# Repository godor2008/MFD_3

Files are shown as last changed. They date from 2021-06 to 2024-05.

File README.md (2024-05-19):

# MFD_3
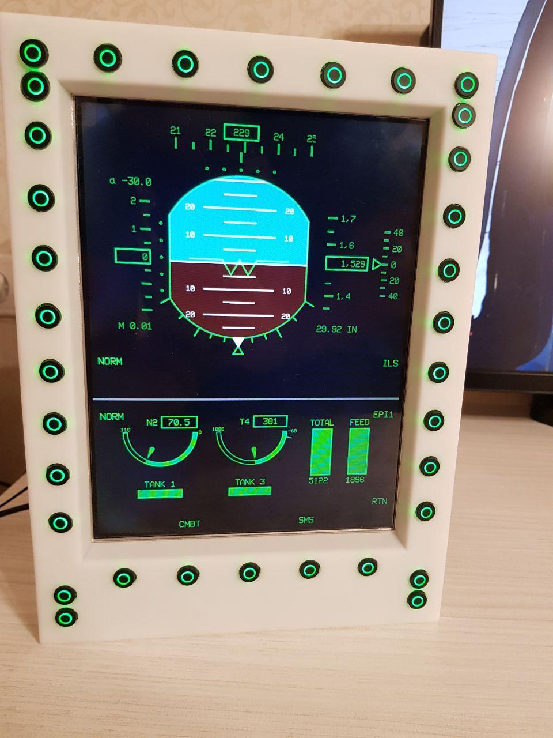
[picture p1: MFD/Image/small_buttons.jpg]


This is MFCD board for JF-17 module used in DCS World. It is similar to Thrustmaster Cougar panel, but larger. Designed to be used with 9.7 inch monitor 4:3 1024x768
Designed in Altium Designer 20

Contains output files (Gerber) and elements list for production at https://jlcpcb.com/

[Gerber zip archive](https://github.com/godor2008/MFD_3/blob/small_buttons/MFD/Project%20Outputs%20for%20Mfd3/Project%20Outputs%20for%20Mfd3.zip)
---------------
[BOM](https://github.com/godor2008/MFD_3/blob/small_buttons/MFD/Project%20Outputs%20for%20Mfd3/Bill%20of%20Materials-Mfd3.xlsx)
-------------
[Pick and Place file](https://github.com/godor2008/MFD_3/blob/small_buttons/MFD/Project%20Outputs%20for%20Mfd3/Pick%20Place%20for%20Mfd3.csv)
-----------
You may download these files and use them to order boards with SMT asssembly at https://jlcpcb.com/

Buttons you have to solder yourself.

Button used is 6*6 tactile switch with built-in LED. For example I used this https://www.aliexpress.com/item/32947533283.html
But you may find other similar buttons at alibaba.com or your local shop.
You may also add simple keycaps, for example I used this https://www.aliexpress.com/item/32918071718.html

Firmware is developed by FreeJoy https://github.com/FreeJoy-Team/FreeJoyWiki
Take a look at that project. 

Firmware may be downloaded [here](https://github.com/godor2008/MFD_3/blob/small_buttons/MFD/Firmware/FreeJoy_v1_7_1b3.hex)

This is [configuration](https://github.com/godor2008/MFD_3/blob/small_buttons/MFD/Firmware/new_FreeJoyLeft.cfg) file that contains mappings between physical and logical buttons. Should be uploaded through FreeJoy configurator after programming firmware.

Additionally you'll need to order:
Tiny [HDMI](https://vi.aliexpress.com/item/33057698628.html) 10 cm cable for extension inside case. Order 2 A1 connectors and 10cm cable


[XH 2.54 20 cm cables](https://vi.aliexpress.com/item/1005002160765607.html) for usb extension. Order 1 pack of each color

[XH 2.54 4 pin angled connectors set](https://vi.aliexpress.com/item/4000029752260.html) for usb extension. You need only two of them, so order minimal pack you can


[Usb Connector B Type vertical](https://vi.aliexpress.com/item/32947971157.html)


| | Price for 1 item, usd |  Quantity | Price |
|---|---:|---:|---:|
| HDMI board from aliexpress | 2,4 | 1 | 2,4 |
| HDMI 10 cm FFC cable | 0,038 | 1 | 0,038 |
| HDMI 10 cm FFC cable Shipping | 1,46 | 1 | 1,46 |
| M4 River Nut | 0,17 | 4 | 0,68 |
| M6 Washer | 0,025 | 4 | 0,1 |
| M3 20 mm brass standoff | 0,16 | 19 | 3,04 |
| M3x8 bolt countersink | 0,025 | 19 | 0,475 |
| M3 14 mm brass male female standoff | 0,16 | 2 | 0,32 |
| M3 washer | 0,024 | 2 | 0,048 |
| Molex HDMI connector | 4,8 | 1 | 4,8 |
| M3 7 mm brass male female standoff  | 0,13 | 2 | 0,26 |
| M3 nylon locking nuts | 0,039 | 4 | 0,156 |
| XH JST 2.54 20 cm cable | 0,055 | 4 | 0,22 |
| M3x10 bolt | 0,04 | 30 | 1,2 |
| M3 nylon locking nuts | 0,039 | 13 | 0,507 |
| M3 nut with washer | 0,025 | 15 | 0,375 |
| M3x10 screw | 0,04 | 19 | 0,76 |
| M2.5x10 bolt | 0,037 | 6 | 0,222 |
| M2.5 nylon locking nut | 0,045 | 11 | 0,495 |
| M3x16 bolt | 0,044 | 2 | 0,088 |
| M4x16 bolt | 0,1 | 4 | 0,4 |
| M2x16 bolt | 0,036 | 9 | 0,324 |
| M2 nylon locking nut | 0,052 | 9 | 0,468 |
| USB-B vertical | 1,58 | 1 | 1,58 |
| USB adapter PCB | 2 | 1 | 2 |
| Main PCB with buttons | 10,47 | 1 | 10,47 |
| LCD with controller | 52 | 1 | 52 |
| 3D printed case | 32 | 1 | 32 |
| Aluminum plates | 13,5 | 2 | 27 |
| KeyCap | 0,146| 32 | 4,672 |
| | | Total USD | 148,558 |

# Some assembly process:

# Middle plate
Make countersink holes so screw perfecty fits in it:


Prepare 19 **brass 20mm standoffs** and 19 **M3 8mm screws**:








Prepare 11 **M3 10mm screws**, 11 **M3 nuts with washer**, 11 **M3 nylon locking nuts**, 11 **small plates from steel 0.8mm-1mm** that will be used to hold LCD on place.


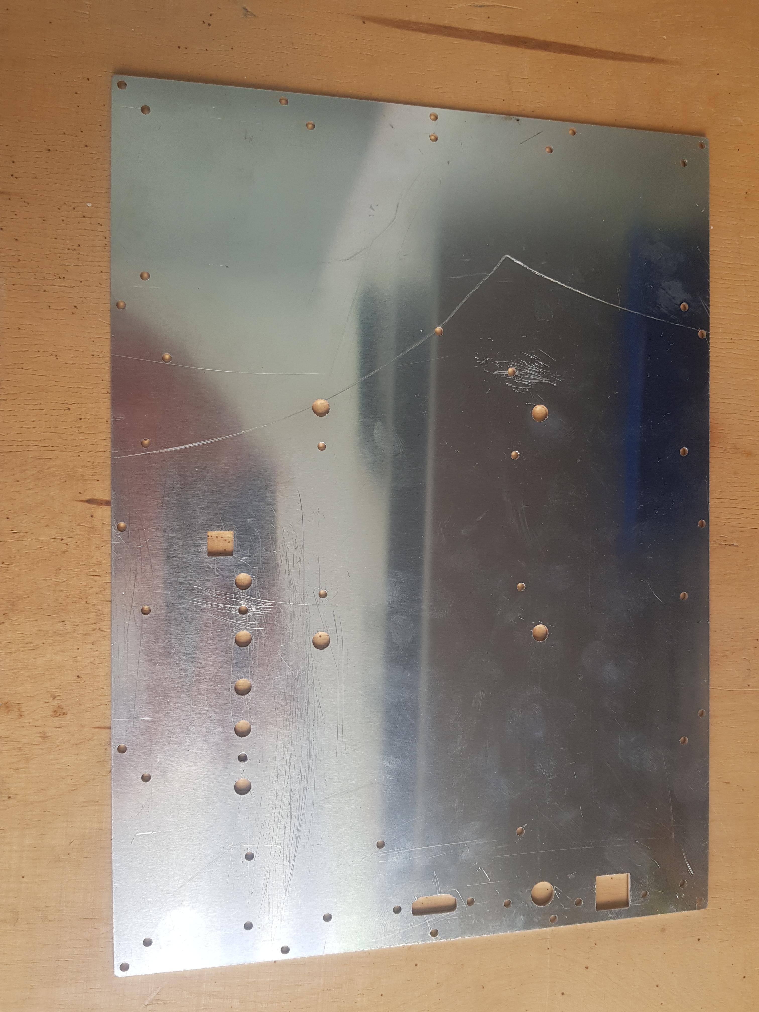
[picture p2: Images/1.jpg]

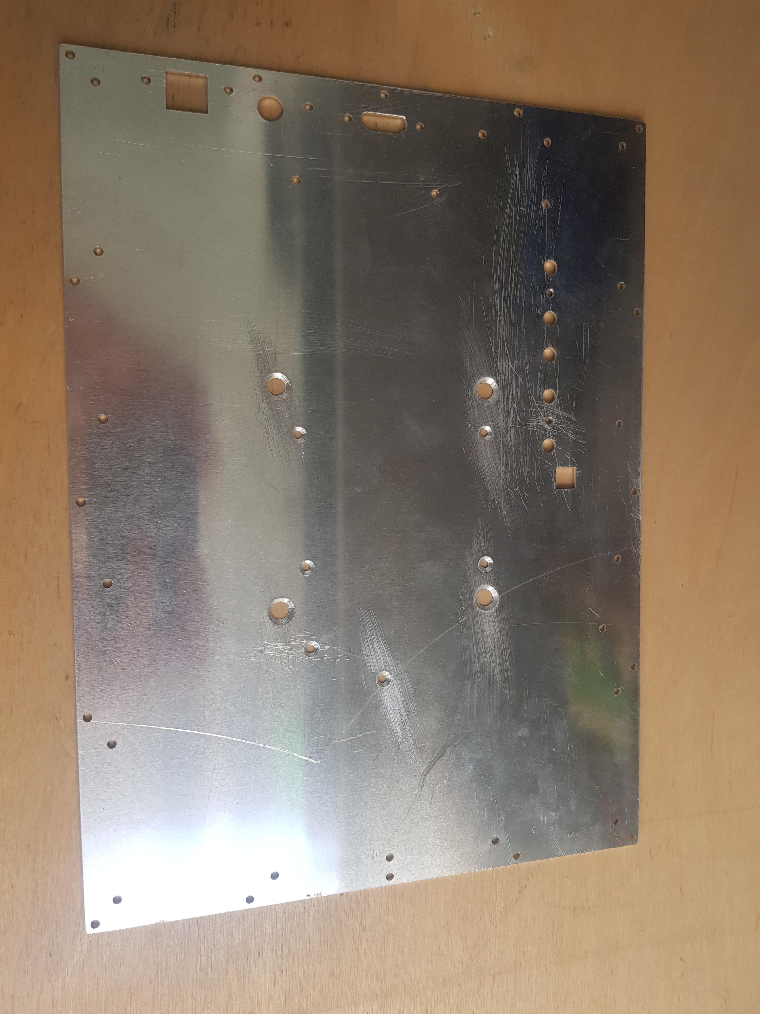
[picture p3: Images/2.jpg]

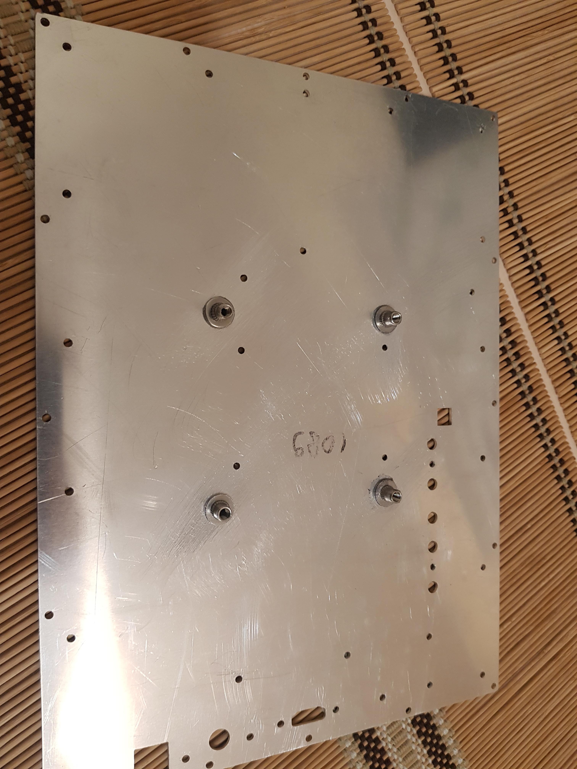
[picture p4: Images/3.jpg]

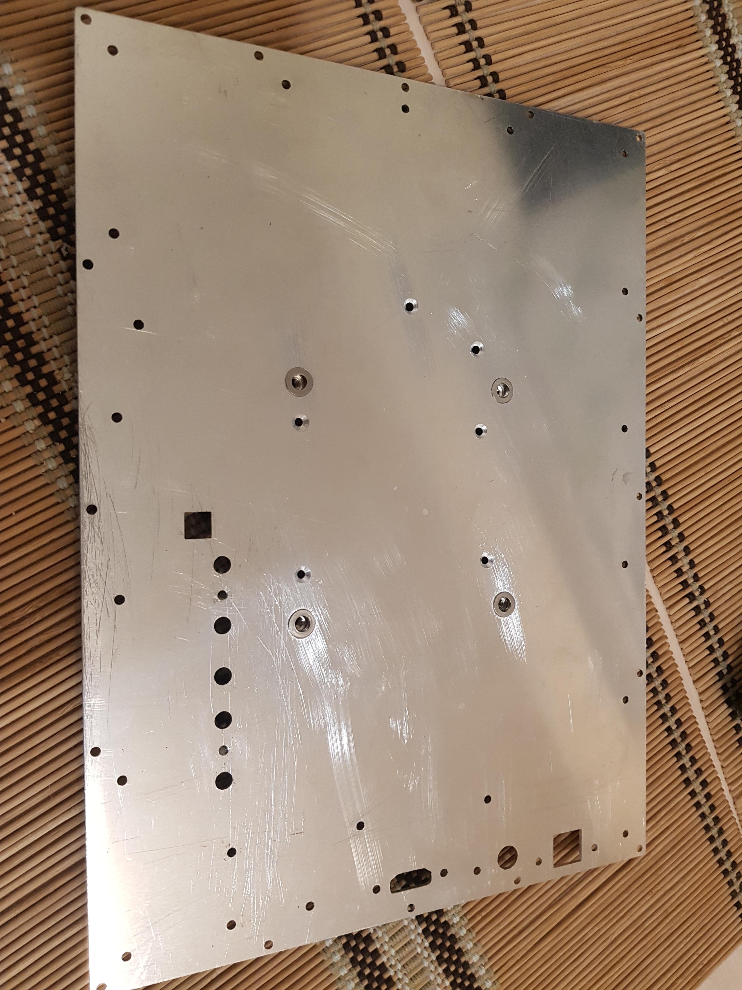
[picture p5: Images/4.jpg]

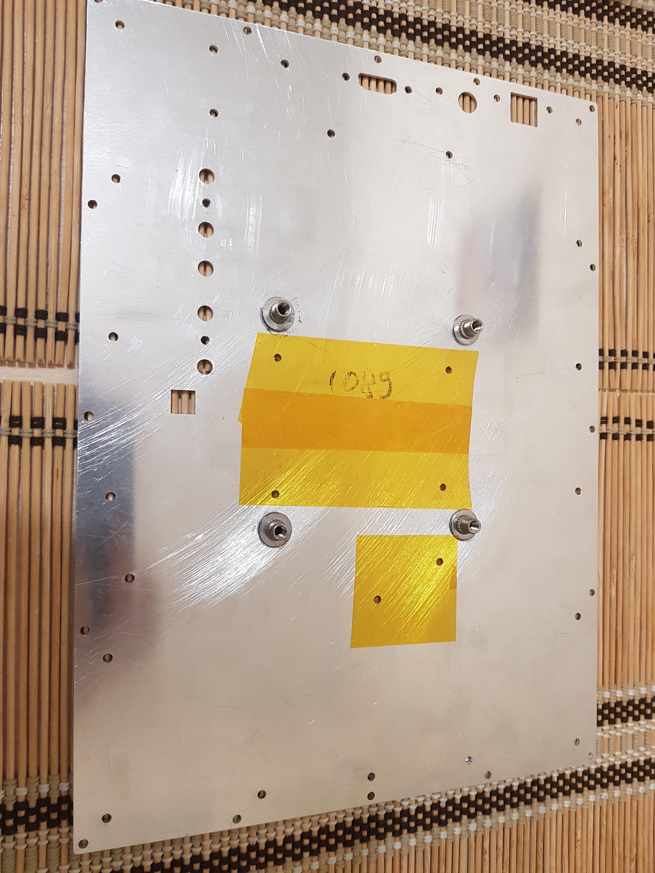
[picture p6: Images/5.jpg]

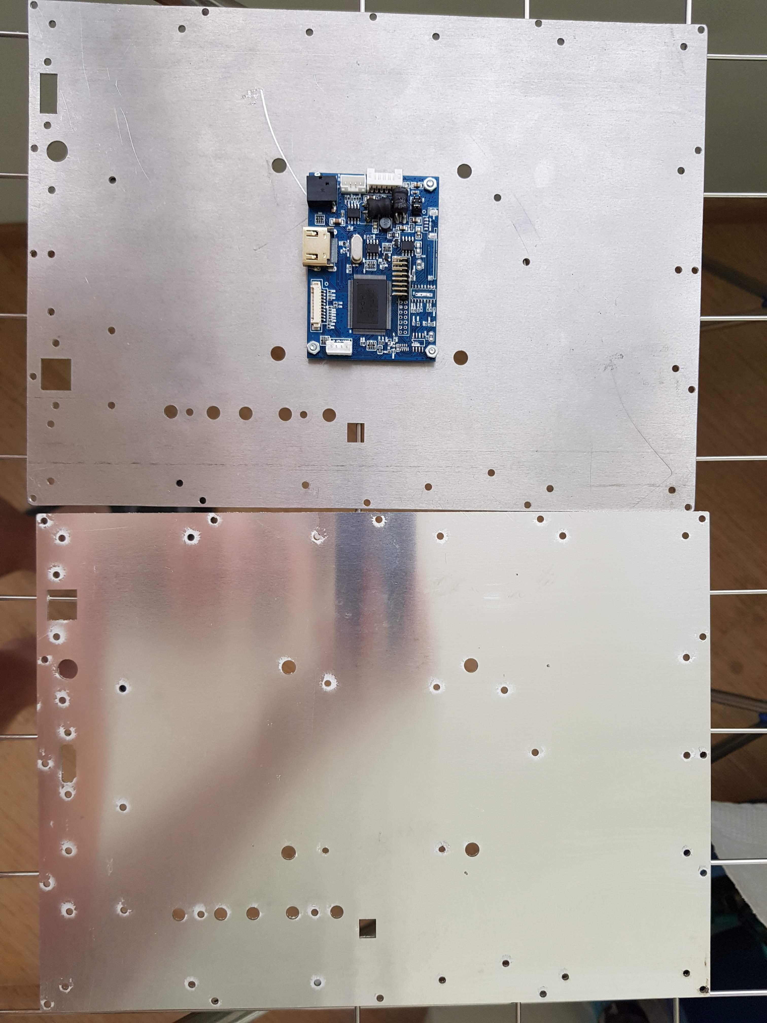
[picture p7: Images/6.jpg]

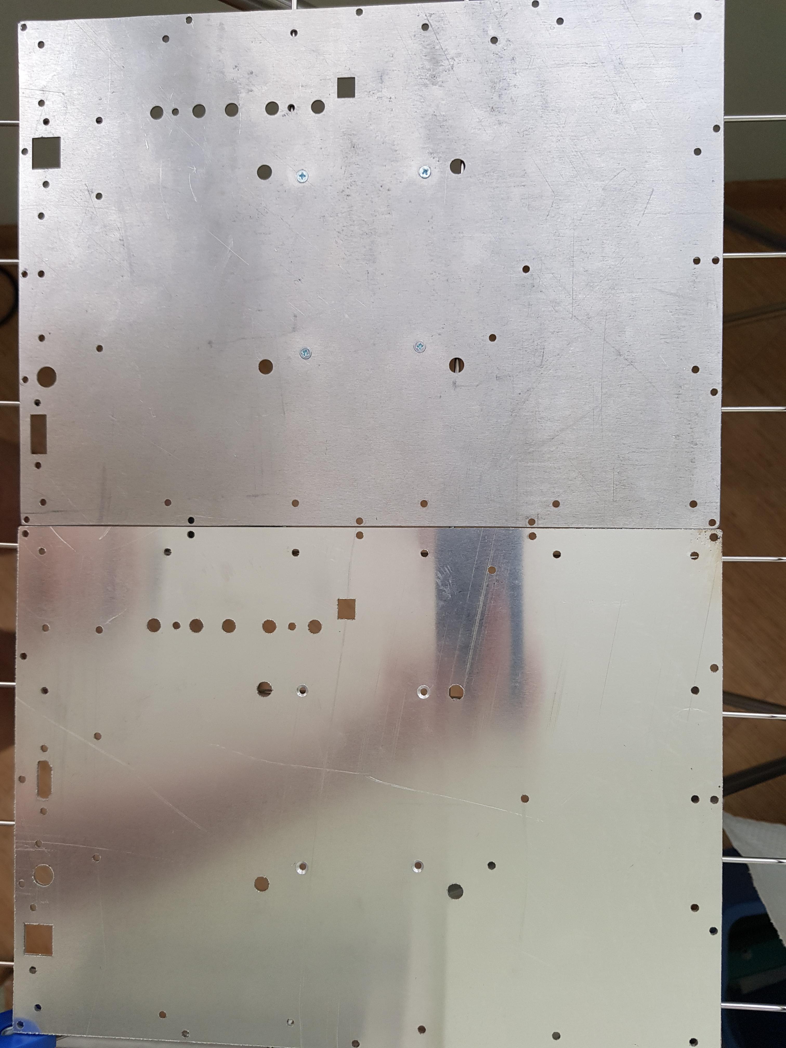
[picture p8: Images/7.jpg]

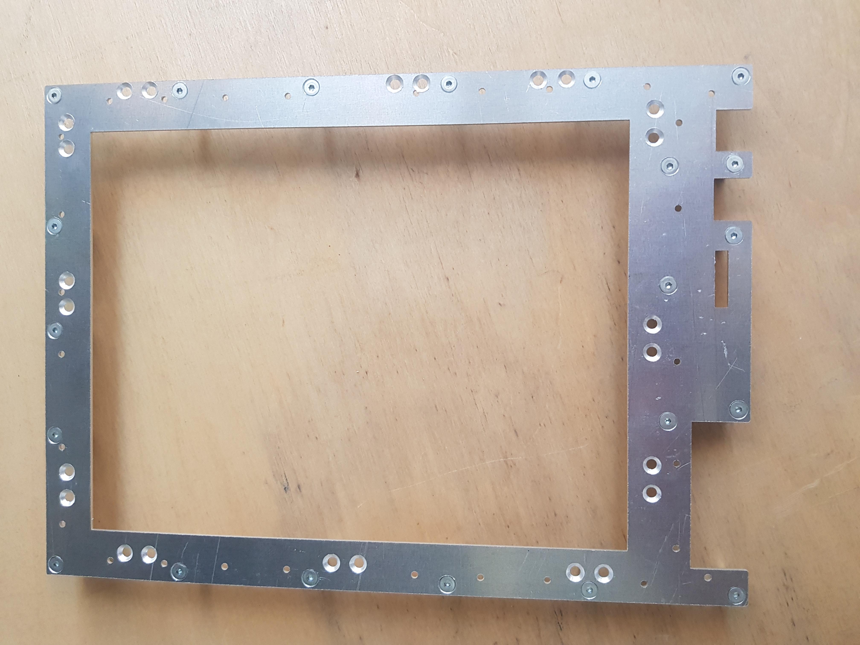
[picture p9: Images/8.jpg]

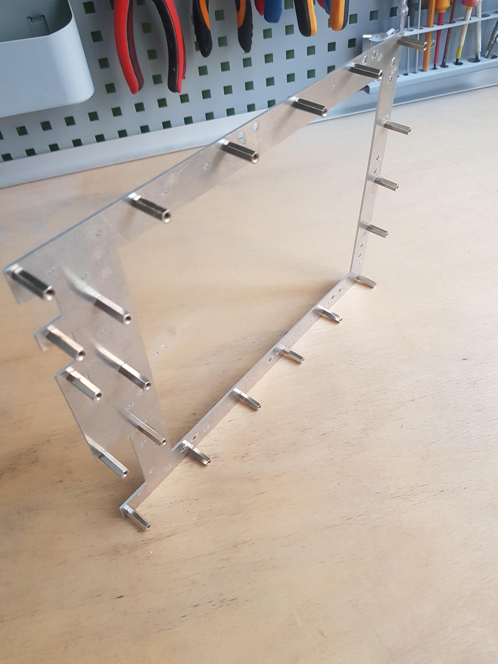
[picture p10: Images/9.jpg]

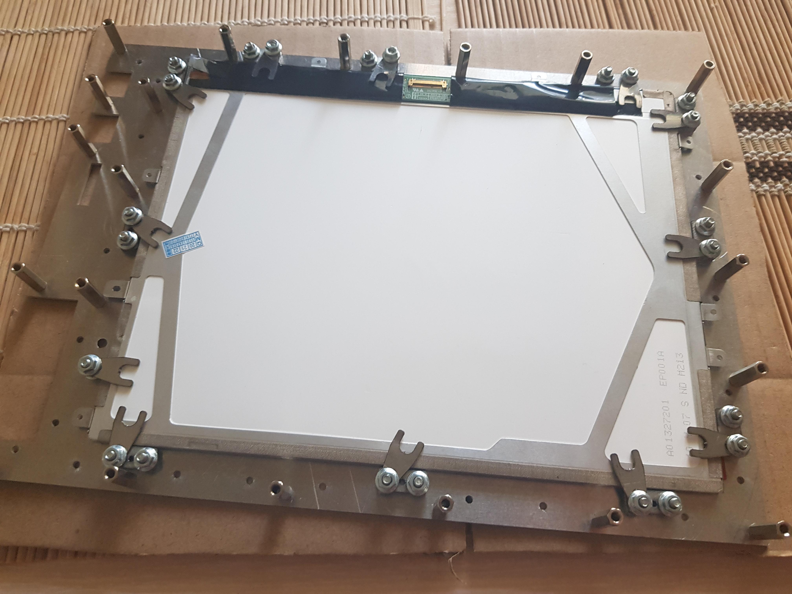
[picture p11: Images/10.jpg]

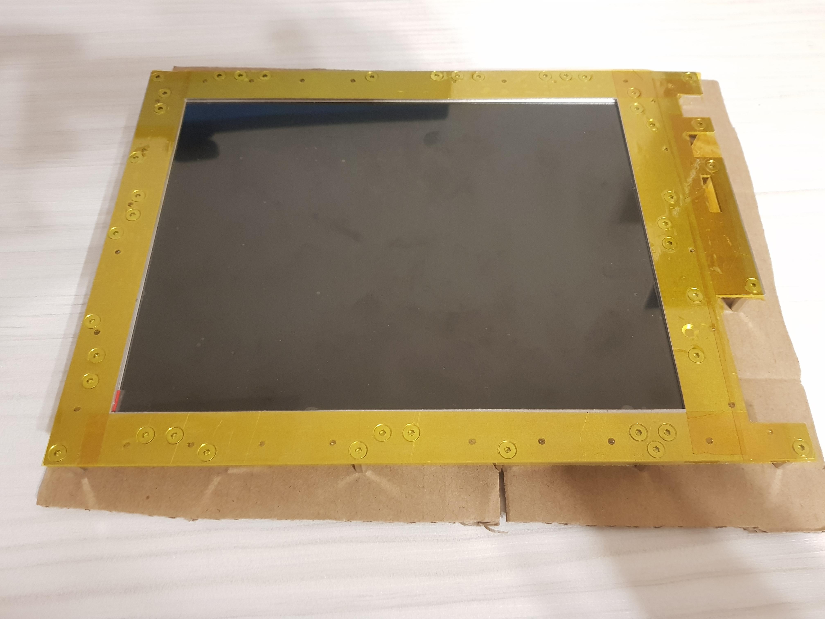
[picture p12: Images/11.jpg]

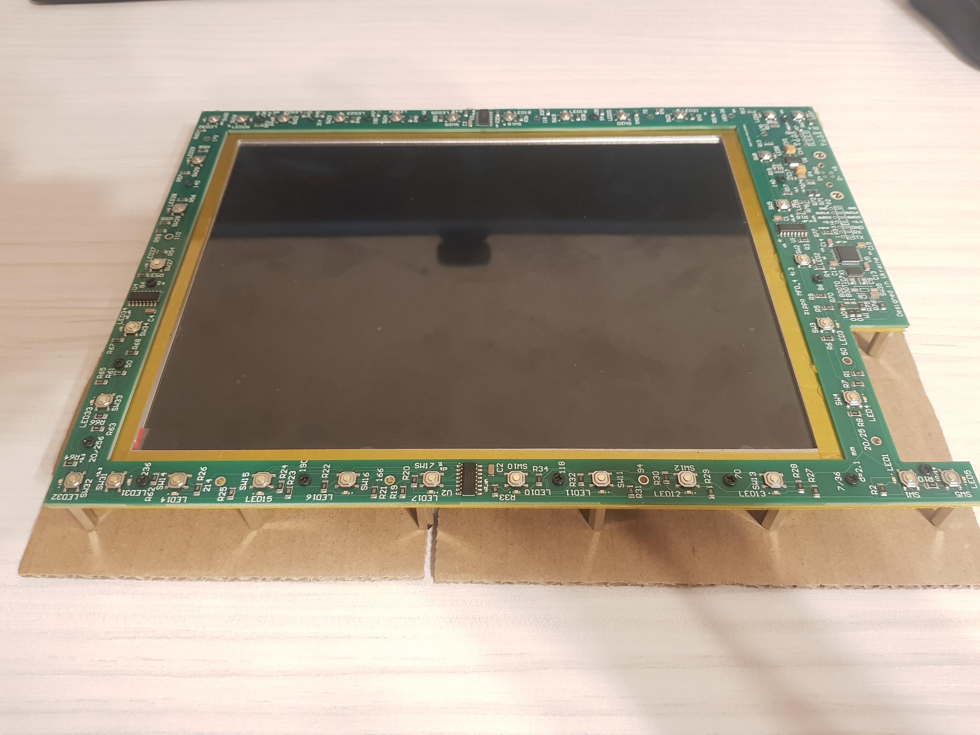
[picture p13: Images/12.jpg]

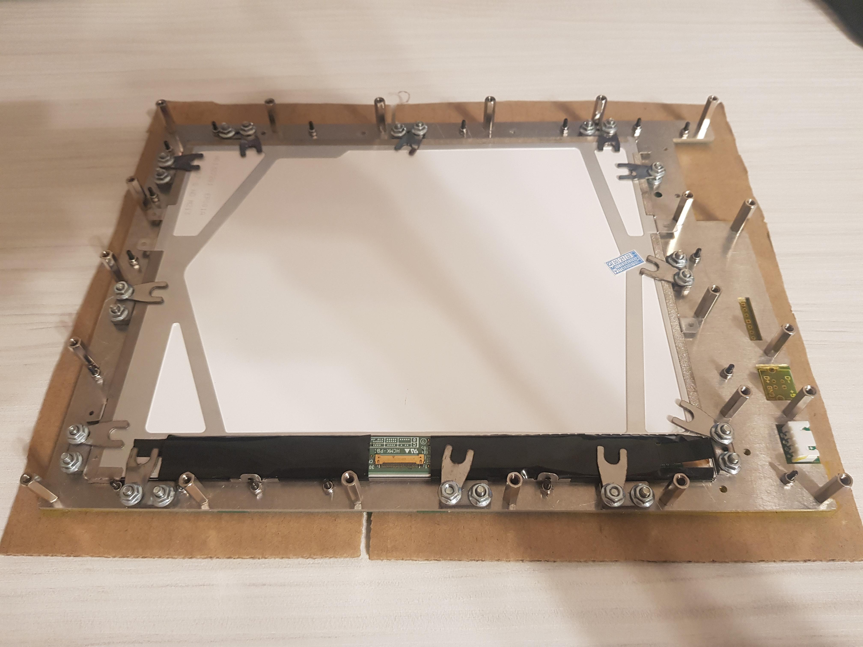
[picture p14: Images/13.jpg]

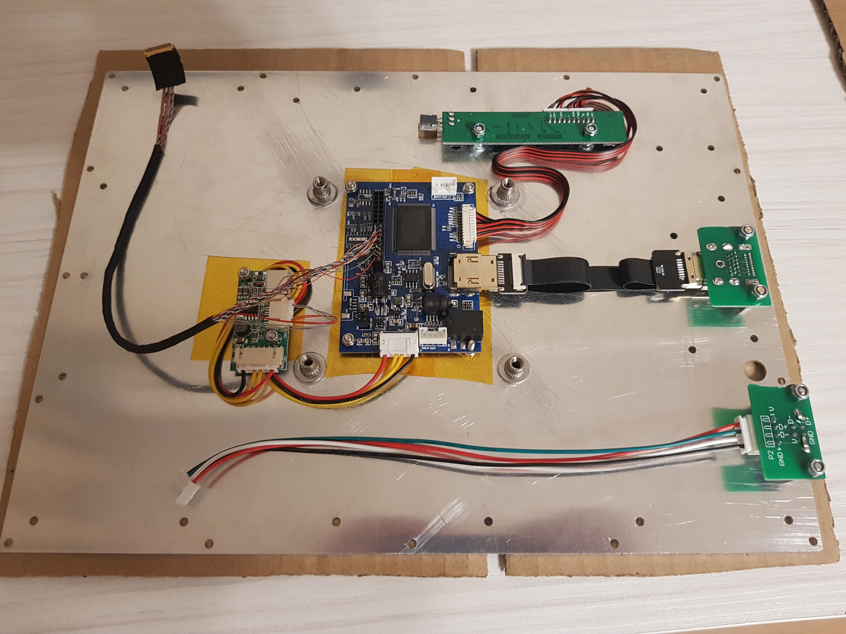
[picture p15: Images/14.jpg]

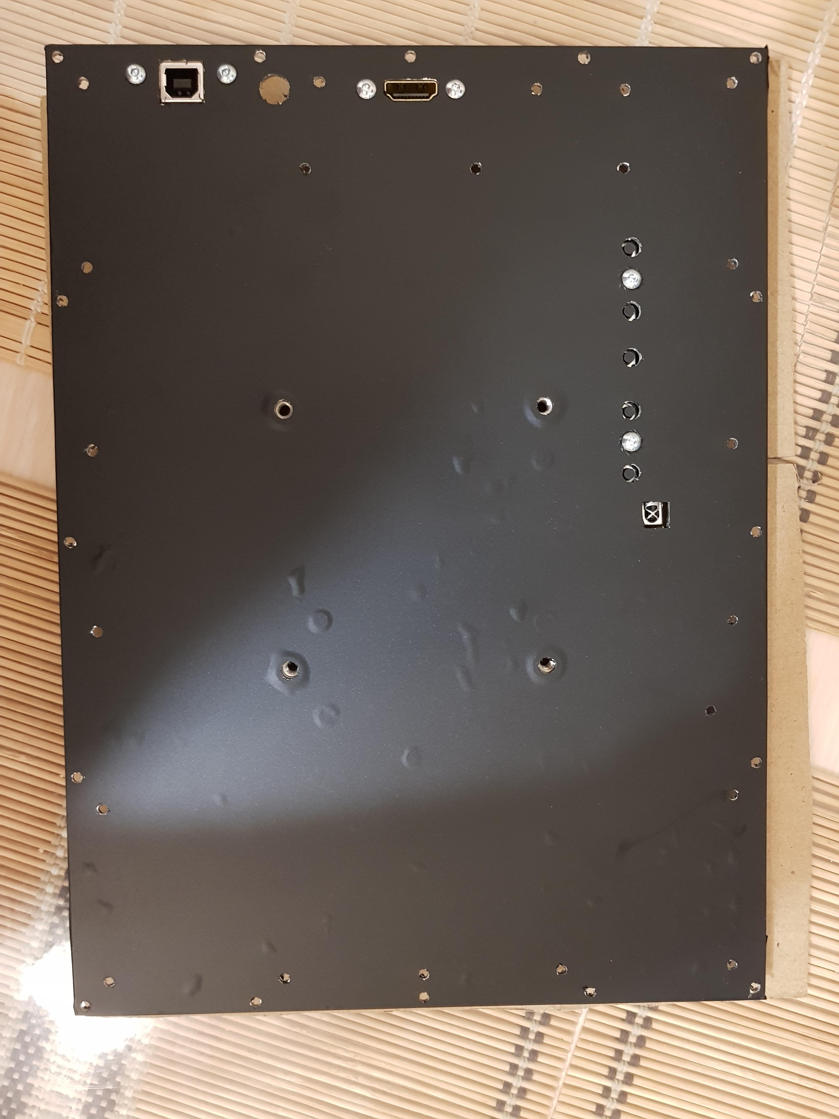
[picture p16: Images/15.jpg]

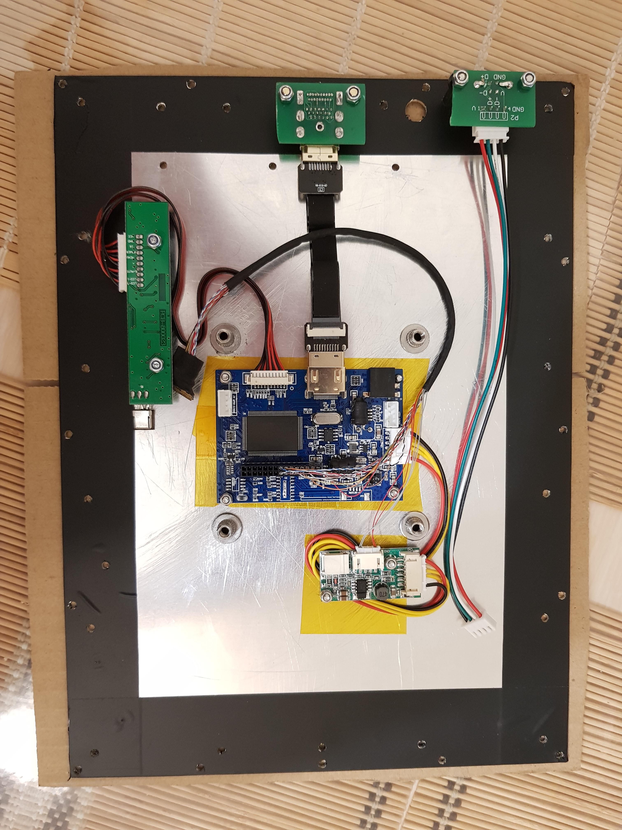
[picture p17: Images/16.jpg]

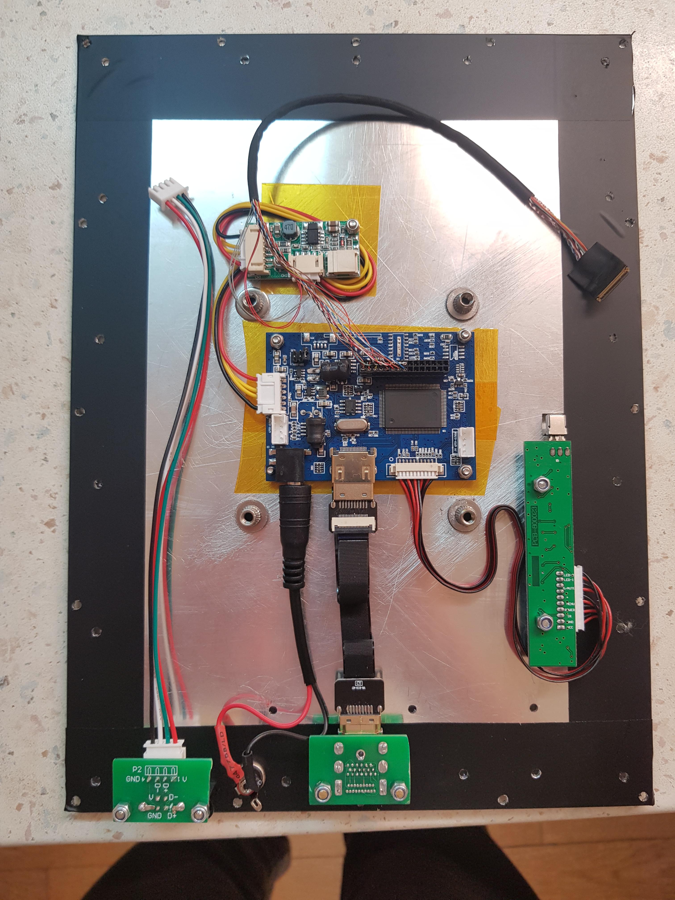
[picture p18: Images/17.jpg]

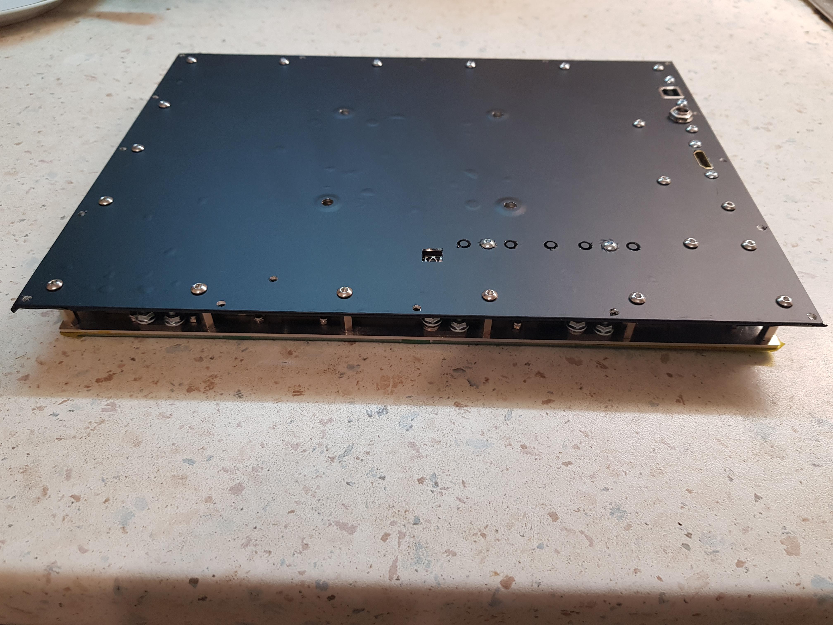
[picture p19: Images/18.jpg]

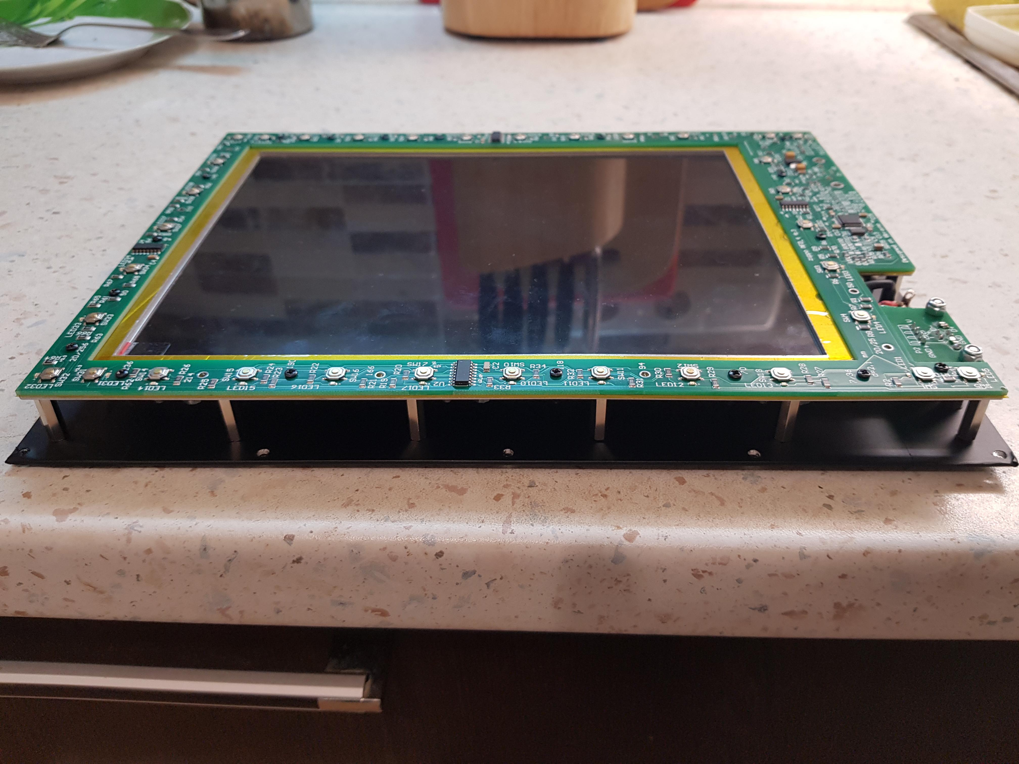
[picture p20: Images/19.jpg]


# HDMI board
Solder **HDMI 47659-1102 Molex** connector and **FFC/FPC 20pin 0.5mm** connector to board. Use board P16. You may use any from the set depending on your prefferable connectors.


Then prepare:
2 **M3 nylon locking nuts** and 2 **M3 Threaded Hex Brass Male Female Standoff 7mm**


And assemble it:


# USB board
Solder **USB-B vertical** and **XH JST 2.54 4 pin male right angled connector**


Then prepare:
2 **M3 nylon locking nuts**, 2 **M3 Threaded Hex Brass Male Female Standoff 14mm**, 2 **M3 washer**. Washers are needed to perfectly match height of USB connector


And assemble it:


# USB cable
Prepare 2 **XH JST 2.54 4 pin female connector** and 4 **XH JST 2.54 20 cm cable**


Then assemble it. Pay attention that green and white wires not symmetrical


Now connect cable to USB board:


# Loading Firmware
Connect STM32 ST-Link programmer to board: SWDIO, SWCLK, GND, +3.3V

Open STM32 ST-Link Utility


Click _Target_ - _Connect_. You should see valid messages in console if connected.


Click _File_ - _Open file_


Select *.hex file and click _Open_


Now _Target_ - _Program & Verify..._


Click _Start_


Progress bar should become green and when done window may be closed. You should see _Verification...OK_ in console


Now disconnect STM32 programmer from board.

# Loading Configuration
Connect board via USB and launch FreeJoyQt configurator. It should have green box and deafult name FreeJoy with version. It means firmware is present on board and we can now upload our configuration for buttons.


Click on _Load config from file_. Navigate to config file and click _Open_


Now click on _Write config to Device_


After successful write, default name on top should change to one of _FreeJoyLeft_/_FreeJoyCenter_/_FreeJoyRight_


Repeat above steps for each MFD by selecting corresponding configuration file. Only things that differ between files are _DeviceName_ and _USB PID_. Different _USB PID_ is required so Windows could distinguish multiple devices when they are connected same time. These settings may be changed in _Advanced_ tab:


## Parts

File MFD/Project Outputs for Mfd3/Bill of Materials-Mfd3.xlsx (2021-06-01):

Comment | Description | Designator | Footprint | Quantity | LCSC Part #
0.1 uF | Chip Capacitor, 1206 | C1, C2, C3, C4, C10, C11, C12, C13, C14, C15 | 1206-CAP | 10 | C24497
20 pF | Chip Capacitor, 1206 | C7, C9 | 0805 CAP | 2 | C1798
1 uF | Chip Capacitor, 1206 | C8 | 1206-CAP | 1 | C1848
100 uF | Tantalum Capacitor, 1210 | C16, C17 | 1210 Cap | 2 | C16133
LED 0603 | LED 0603 | LED1, LED2, LED3, LED4, LED5, LED6, LED7, LED8, LED9, LED10, LED11, LED12, LED13, LED14, LED15, LED16, LED17, LED18, LED19, LED20, LED21, LED22, LED23, LED24, LED25, LED26, LED27, LED28, LED29, LED30, LED31, LED32, LED33, LED34 | LED 0603 | 34 | C72043
PLD 1X4H | Header, 4-Pin, SIngle row, Right Angle | P2, P7 | PLD 1X4H | 2
PLD 1X3H | Header, 3-Pin, SIngle row, Right Angle | P3 | PLD 1X3H | 1
USB-B_Vertical |  | P4 | USB-B_Vertical | 1
10K | Resistor 1206 | R1, R3, R5, R7, R9, R11, R13, R15, R17, R19, R21, R23, R25, R27, R29, R31, R33, R35, R37, R39, R41, R43, R45, R47, R49, R51, R53, R55, R57, R59, R61, R63, R65, R67, R76, R77, R78 | 1206 | 37 | C17902
4.7K | Resistor 1206 | R2, R4, R6, R8, R10, R12, R14, R16, R18, R20, R22, R24, R26, R28, R30, R32, R34, R36, R38, R40, R42, R44, R46, R48, R50, R52, R54, R56, R58, R60, R62, R64, R66, R68 | 1206 | 34 | C17936
100K | Resistor 1206 | R70, R75 | 1206 | 2 | C17900
20 | Resistor 1206 | R71, R72 | 1206 | 2 | C17955
1.5K | Resistor 0805 | R74 | 0805 RES | 1 | C4310
TACT SWITCH 5.2mm | Push button 5.2 mm | SW1, SW2, SW3, SW4, SW5, SW6, SW7, SW8, SW9, SW10, SW11, SW12, SW13, SW14, SW15, SW16, SW17, SW18, SW19, SW20, SW21, SW22, SW23, SW24, SW25, SW26, SW27, SW28, SW29, SW30, SW31, SW32, SW33, SW34 | TACT SWITCH 5.2mm | 34 | C412369
 | WS-TASV SMD Tact Switch 6.0X3.5 mm | SW35 | PushButton | 1
74HC165D,653 | 8-Bit Parallel-Load Shift Registers, SOIC-16, LARGE T&R | U1, U2, U3, U4 | SOIC-16 | 4 | C5613
STM32F103C8T6 | ARM Cortex-M3 32-bit MCU, 64 KB Flash, 20 KB Internal RAM, 37 I/Os, 48-pin LQFP, -40 to 85 degC, Tray | U5 | STM-LQFP48_N | 1 | C8734
AMS1117-3.3 | LDO Voltage Regulators 1A, 3.3V | U6 | FP-AMS1117-IPC_A | 1 | C6186
0R | Resistor 1206 | W0, W1 | 1206 | 2 | C17888
8MHz | Miniature Ceramic Crystal, 8 MHz, -40 to 85 degC, 2-Pin SMD, RoHS, Tape and Reel | X1 | ABRA-ABM3-2_V | 1 | C115962

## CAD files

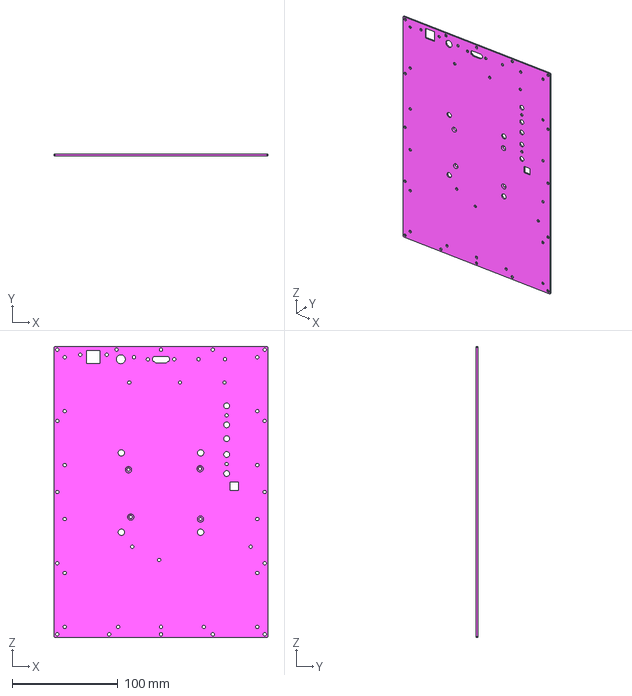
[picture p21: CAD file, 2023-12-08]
MCAD/Lasercut aluminium/Bottom_1_5mm.step
202.0 x 1.50 x 275.1 mm

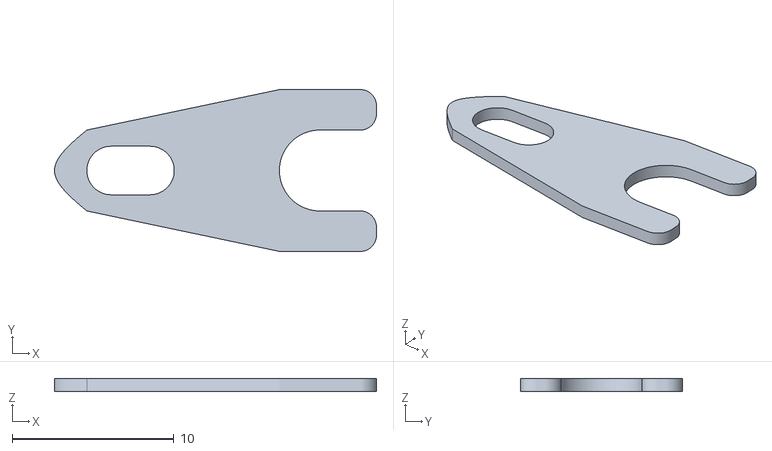
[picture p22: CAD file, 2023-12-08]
MCAD/Lasercut steel/LCD_holder_0,8mm.stl
19.9 x 10.0 x 0.8

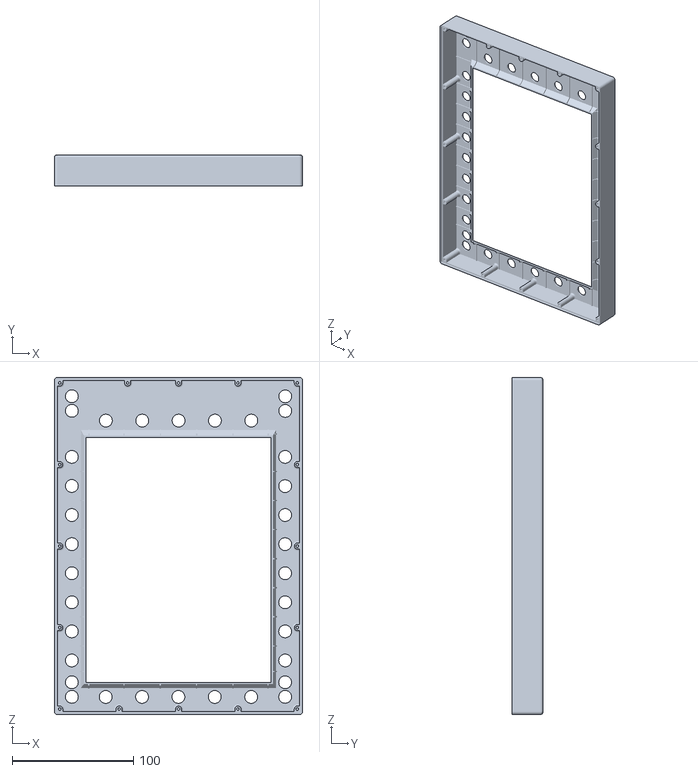
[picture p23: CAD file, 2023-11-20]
MCAD/WholeCase/PlasticTop.stl
205.0 x 25.7 x 278.1

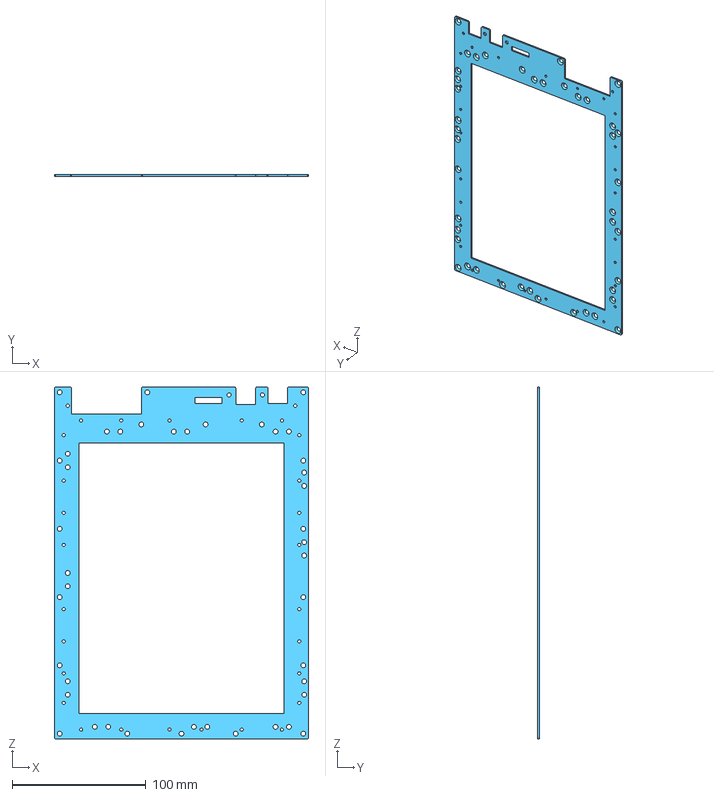
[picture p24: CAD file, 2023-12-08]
MCAD/Lasercut aluminium/Middle_1_5mm.step
190.0 x 1.50 x 263.0 mm

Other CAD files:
MCAD/Lasercut steel/holder_3mm.dwg
MCAD/Lasercut aluminium/Bottom_1_5mm.dwg
MCAD/Lasercut aluminium/Bottom_1_5mm.dxf
MCAD/Lasercut aluminium/Bottom_1_5mm.stl
MCAD/Lasercut aluminium/Middle_1_5mm.dwg
MCAD/Lasercut aluminium/Middle_1_5mm.dxf
MCAD/Lasercut aluminium/Middle_1_5mm.stl
MCAD/Lasercut steel/LCD_holder_0,8mm.dwg

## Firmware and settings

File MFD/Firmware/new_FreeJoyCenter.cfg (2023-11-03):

[DeviceUsbConfig]
FirmwareVersion=1713
DeviceName=FreeJoyCenter
Vid=483
Pid=5760
USBExchange=5

[PinsConfig]
A0=0
A1=0
A2=0
A3=0
A4=0
A5=0
A6=0
A7=0
A8=0
A9=0
A10=0
A15=0
B0=0
B1=0
B3=28
B4=0
B5=0
B6=0
B7=0
B8=0
B9=19
B10=2
B11=2
B12=20
B13=0
B14=0
B15=0
C13=0
C14=0
C15=0

[ShiftConfig]
Shift0=-1
Shift1=-1
Shift2=-1
Shift3=-1
Shift4=-1

[TimersConfig]
Timer1=50
Timer2=200
Timer3=300
Debounce=50
EncoderPress=30

[ButtonsConfig_0]
ButtonPhysicNumber=17
ButtonType=0
ShiftMod=0
Inverted=0
Disabled=0
DelayTimer=0
PressTimer=0

[ButtonsConfig_1]
ButtonPhysicNumber=16
ButtonType=0
ShiftMod=0
Inverted=0
Disabled=0
DelayTimer=0
PressTimer=0

[ButtonsConfig_2]
ButtonPhysicNumber=23
ButtonType=0
ShiftMod=0
Inverted=0
Disabled=0
DelayTimer=0
PressTimer=0

[ButtonsConfig_3]
ButtonPhysicNumber=22
ButtonType=0
ShiftMod=0
Inverted=0
Disabled=0
DelayTimer=0
PressTimer=0

[ButtonsConfig_4]
ButtonPhysicNumber=21
ButtonType=0
ShiftMod=0
Inverted=0
Disabled=0
DelayTimer=0
PressTimer=0

[ButtonsConfig_5]
ButtonPhysicNumber=11
ButtonType=0
ShiftMod=0
Inverted=0
Disabled=0
DelayTimer=0
PressTimer=0

[ButtonsConfig_6]
ButtonPhysicNumber=10
ButtonType=0
ShiftMod=0
Inverted=0
Disabled=0
DelayTimer=0
PressTimer=0

[ButtonsConfig_7]
ButtonPhysicNumber=9
ButtonType=0
ShiftMod=0
Inverted=0
Disabled=0
DelayTimer=0
PressTimer=0

[ButtonsConfig_8]
ButtonPhysicNumber=8
ButtonType=0
ShiftMod=0
Inverted=0
Disabled=0
DelayTimer=0
PressTimer=0

[ButtonsConfig_9]
ButtonPhysicNumber=15
ButtonType=0
ShiftMod=0
Inverted=0
Disabled=0
DelayTimer=0
PressTimer=0

[ButtonsConfig_10]
ButtonPhysicNumber=14
ButtonType=0
ShiftMod=0
Inverted=0
Disabled=0
DelayTimer=0
PressTimer=0

[ButtonsConfig_11]
ButtonPhysicNumber=13
ButtonType=0
ShiftMod=0
Inverted=0
Disabled=0
DelayTimer=0
PressTimer=0

[ButtonsConfig_12]
ButtonPhysicNumber=12
ButtonType=0
ShiftMod=0
Inverted=0
Disabled=0
DelayTimer=0
PressTimer=0

[ButtonsConfig_13]
ButtonPhysicNumber=1
ButtonType=0
ShiftMod=0
Inverted=0
Disabled=0
DelayTimer=0
PressTimer=0

[ButtonsConfig_14]
ButtonPhysicNumber=0
ButtonType=0
ShiftMod=0
Inverted=0
Disabled=0
DelayTimer=0
PressTimer=0

[ButtonsConfig_15]
ButtonPhysicNumber=7
ButtonType=0
ShiftMod=0
Inverted=0
Disabled=0
DelayTimer=0
PressTimer=0

[ButtonsConfig_16]
ButtonPhysicNumber=6
ButtonType=0
ShiftMod=0
Inverted=0
Disabled=0
DelayTimer=0
PressTimer=0

[ButtonsConfig_17]
ButtonPhysicNumber=5
ButtonType=0
ShiftMod=0
Inverted=0
Disabled=0
DelayTimer=0
PressTimer=0

[ButtonsConfig_18]
ButtonPhysicNumber=27
ButtonType=0
ShiftMod=0
Inverted=0
Disabled=0
DelayTimer=0
PressTimer=0

[ButtonsConfig_19]
ButtonPhysicNumber=26
ButtonType=0
ShiftMod=0
Inverted=0
Disabled=0
DelayTimer=0
PressTimer=0

[ButtonsConfig_20]
ButtonPhysicNumber=25
ButtonType=0
ShiftMod=0
Inverted=0
Disabled=0
DelayTimer=0
PressTimer=0

[ButtonsConfig_21]
ButtonPhysicNumber=24
ButtonType=0
ShiftMod=0
Inverted=0
Disabled=0
DelayTimer=0
PressTimer=0

[ButtonsConfig_22]
ButtonPhysicNumber=31
ButtonType=0
ShiftMod=0
Inverted=0
Disabled=0
DelayTimer=0
PressTimer=0

[ButtonsConfig_23]
ButtonPhysicNumber=30
ButtonType=0
ShiftMod=0
Inverted=0
Disabled=0
DelayTimer=0
PressTimer=0

[ButtonsConfig_24]
ButtonPhysicNumber=29
ButtonType=0
ShiftMod=0
Inverted=0
Disabled=0
DelayTimer=0
PressTimer=0

[ButtonsConfig_25]
ButtonPhysicNumber=28
ButtonType=0
ShiftMod=0
Inverted=0
Disabled=0
DelayTimer=0
PressTimer=0

[ButtonsConfig_26]
ButtonPhysicNumber=19
ButtonType=0
ShiftMod=0
Inverted=0
Disabled=0
DelayTimer=0
PressTimer=0

[ButtonsConfig_27]
ButtonPhysicNumber=18
ButtonType=0
ShiftMod=0
Inverted=0
Disabled=0
DelayTimer=0
PressTimer=0

[ButtonsConfig_28]
ButtonPhysicNumber=20
ButtonType=0
ShiftMod=0
Inverted=0
Disabled=0
DelayTimer=0
PressTimer=0

[ButtonsConfig_29]
ButtonPhysicNumber=33
ButtonType=0
ShiftMod=0
Inverted=0
Disabled=0
DelayTimer=0
PressTimer=0

[ButtonsConfig_30]
ButtonPhysicNumber=3
ButtonType=0
ShiftMod=0
Inverted=0
Disabled=0
DelayTimer=0
PressTimer=0

[ButtonsConfig_31]
ButtonPhysicNumber=2
ButtonType=0
ShiftMod=0
Inverted=0
Disabled=0
DelayTimer=0
PressTimer=0

[ButtonsConfig_32]
ButtonPhysicNumber=4
ButtonType=0
ShiftMod=0
Inverted=0
Disabled=0
DelayTimer=0
PressTimer=0

[ButtonsConfig_33]
ButtonPhysicNumber=32
ButtonType=0
ShiftMod=0
Inverted=0
Disabled=0
DelayTimer=0
PressTimer=0

[ButtonsConfig_34]
ButtonPhysicNumber=-1
ButtonType=0
ShiftMod=0
Inverted=0
Disabled=0
DelayTimer=0
PressTimer=0

[ButtonsConfig_35]
ButtonPhysicNumber=-1
ButtonType=0
ShiftMod=0
Inverted=0
Disabled=0
DelayTimer=0
PressTimer=0

[ButtonsConfig_36]
ButtonPhysicNumber=-1
ButtonType=0
ShiftMod=0
Inverted=0
Disabled=0
DelayTimer=0
PressTimer=0

[ButtonsConfig_37]
ButtonPhysicNumber=-1
ButtonType=0
ShiftMod=0
Inverted=0
Disabled=0
DelayTimer=0
PressTimer=0

[ButtonsConfig_38]
ButtonPhysicNumber=-1
ButtonType=0
ShiftMod=0
Inverted=0
Disabled=0
DelayTimer=0
PressTimer=0

[ButtonsConfig_39]
ButtonPhysicNumber=-1
ButtonType=0
ShiftMod=0
Inverted=0
Disabled=0
DelayTimer=0
PressTimer=0
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

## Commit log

2020-08-28 fist commit
    [Mfd3.PcbDoc, Mfd3.PrjPcb, Mfd3.SchDoc]
2020-08-28 missed net
    [Mfd3.PcbDoc]
2020-08-28 minor change
    [Mfd3.PcbDoc]
2020-09-10 Added output files
    [Bill of Materials-Mfd3.xlsx, Pick Place for Mfd3.csv]
2020-09-10 Added firmware for STM32
2021-06-01 Version of board with small 5.1x5.1 smd tactile buttons
    [Bill of Materials-Mfd3.xlsx, Mfd3.PcbDoc, Mfd3.PrjPcb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]
2021-11-11 Added step model of whole case
2023-11-03 Add files via upload
    Added configs for 1.7.3 version
    [new_FreeJoyCenter.cfg, new_FreeJoyLeft.cfg, new_FreeJoyRight.cfg]
